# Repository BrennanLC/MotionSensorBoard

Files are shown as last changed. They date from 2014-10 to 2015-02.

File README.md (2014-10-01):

Motion Sensor Board
==============

Wireless motion sensor board that interfaces with parallax PIR sensor.
Board uses the Attiny2313A microcontroller. wireless capability provided by Xbee Pro Series 2 module.

Current version of motion sensor board verified on 9/28/14

Files:

MotionSensorsch.pdf - Copy of board schematic in PDF format
MotionSensorBoard.sch - Board schematic eagle file 
MotionSensorBoard.brd - Board layout eagle file
MotionSensorBoard.pdf - Board layout in PDF format
Gerbers.zip - Gerber board files

schematic and board layout built with Eagle 6.4.0 Standard. More info and 
download available here:

https://www.cadsoftusa.com/

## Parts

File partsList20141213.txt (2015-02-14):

Partlist exported from /Users/BrennanC/Documents/Projects/GitHub/MotionSensorBoard/MotionSensorBoard.sch at 12/13/14 2:37 PM

Part      Value            Device                    Package          Description                                                                                                                              DIGIKEYPART#            PROD_ID     VALUE     
C1        10uF             CAP_POL_AL                PANASONIC_BMIN   Panasonic Aluminum Electrolytic Capacitor Package B                                                                                                                                    
C2        10uF             CAP_POL_AL                PANASONIC_BMIN   Panasonic Aluminum Electrolytic Capacitor Package B                                                                                                                                    
C3        0.1uF            CAP0603-CAP               0603-CAP         Capacitor                                                                                                                                                                              
C4        0.1uF            CAP0603-CAP               0603-CAP         Capacitor                                                                                                                                                                              
C7        10uF             CAP_POL_AL                PANASONIC_BMIN   Panasonic Aluminum Electrolytic Capacitor Package B                                                                                                                                    
CC_TEXT1  CREATIVE_COMMONS CREATIVE_COMMONS          CREATIVE_COMMONS Creative Commons License summary                                                                                                                                                       
J1        PRGM             AVR_SPI_PRG_6PTH          2X3              AVR ISP 6 Pin                                                                                                                                                                          
J2        POWER_JACKPTH    POWER_JACKPTH             POWER_JACK_PTH   Power Jack                                                                                                                                                                             
JP1                        M03PTH                    1X03             Header 3                                                                                                                                                                               
JP4       M02PTH           M02PTH                    1X02             Standard 2-pin 0.1" header. Use with                                                                                                                                                   
LED4                       LED0603                   LED-0603         LEDs                                                                                                                                                                                   
Q1        BSS138           MOSFET-NCHANNELBSS123LT1G SOT23            Common NMOSFET Parts                                                                                                                                             TRANS-08345           
Q2        BSS138           MOSFET-NCHANNELBSS123LT1G SOT23            Common NMOSFET Parts                                                                                                                                             TRANS-08345           
R1        10k              RESISTOR0603-RES          0603-RES         Resistor                                                                                                                                                                               
R2        4.7k             RESISTOR0603              0603-RES         Resistor                                                                                                                                                                               
R3        4.7k             RESISTOR0603              0603-RES         Resistor                                                                                                                                                                               
R4        PHOTOCELLPTH     PHOTOCELLPTH              PHOTOCELL        CdS photoresistor. This is a low cost way to detect light levels. Resistance decreases with more incoming light. SparkFun SKU: SEN-09088                                               
R5        10k              RESISTOR0603              0603-RES         Resistor                                                                                                                                                                               
R6        4.7k             RESISTOR0603              0603-RES         Resistor                                                                                                                                                                               
R7        4.7k             RESISTOR0603              0603-RES         Resistor                                                                                                                                                                               
R10       270              RESISTOR0603-RES          0603-RES         Resistor                                                                                                                                                                               
STANDOFF1 STAND-OFF        STAND-OFF                 STAND-OFF        #4 Stand Off                                                                                                                                                                           
STANDOFF2 STAND-OFF        STAND-OFF                 STAND-OFF        #4 Stand Off                                                                                                                                                                           
STANDOFF3 STAND-OFF        STAND-OFF                 STAND-OFF        #4 Stand Off                                                                                                                                                                           
STANDOFF4 STAND-OFF        STAND-OFF                 STAND-OFF        #4 Stand Off                                                                                                                                                                           
U$2       XBEE-1B1         XBEE-1B1                  XBEE-1           Xbee module footprints                                                                                                                                                                 
U2        ISO7221ADR       ISO7221ADR                SO08             ISO7221 Dual Channel Digital Isolator from Texas Instruments. See Datasheet for more info Datasheet                                      296-21955-1-ND                                
U3        BMP180           BMP180                    BMP180           BOSCH BMP180 DIGITAL BAROMETRIC PRESSURE SENSOR                                                                                                                                        
U4        NCP1117ST50T3G   NCP1117ST50T3G            SOT223           NCP1117 5V, 1.0 A Low-Dropout Positive Fixed and Adjustable Voltage Regulator  Datasheet                                                 NCP1117ST50T3GOSCT-ND                         
U5        LM1117MPX-3.3    LM1117MPX-3.3             SOT223           3.3V Low Dropout Regulator, 0.8A output. See datasheet for more info Datasheet                                                           LM1117MPX-3.3/NOPBCT-ND                       
U6        HTU21DSMD        HTU21DSMD                 HTU21D                                                                                                                                                                                                  
U7        ATMEGA328P       ATMEGA328_SMT             TQFP32-08        32-Pin Atmega328 part                                                                                                                                            IC-09069    ATMEGA328P

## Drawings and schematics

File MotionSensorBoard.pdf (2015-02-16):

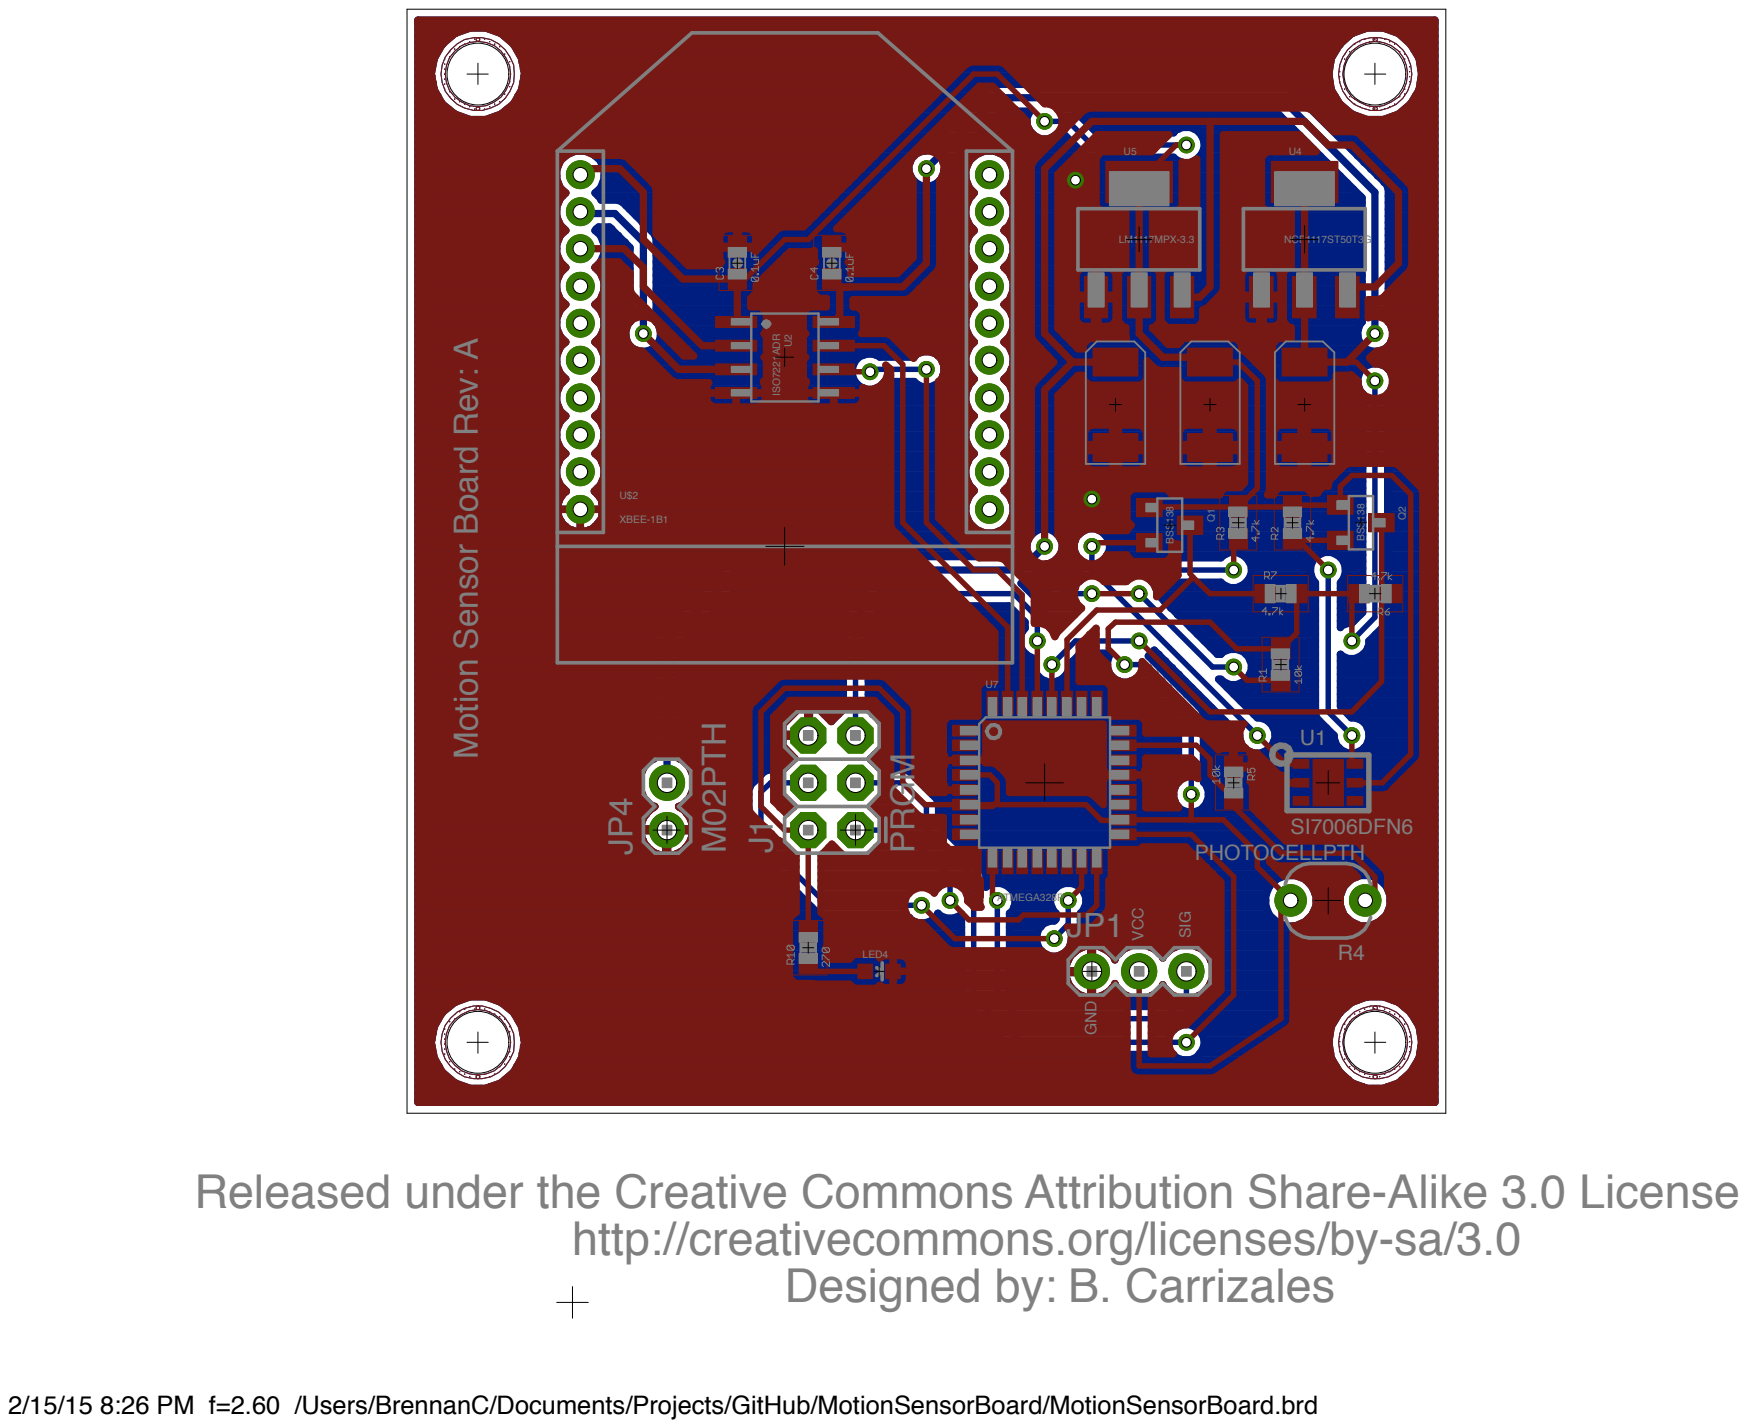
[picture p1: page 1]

LM1117MPX-3.3 | NCP1117ST50T3G

XBEE-1B1

Released under the Creative Commons Attribution Share-Alike 3.0 License

http://creativecommons.org/licenses/by-sa/3.0

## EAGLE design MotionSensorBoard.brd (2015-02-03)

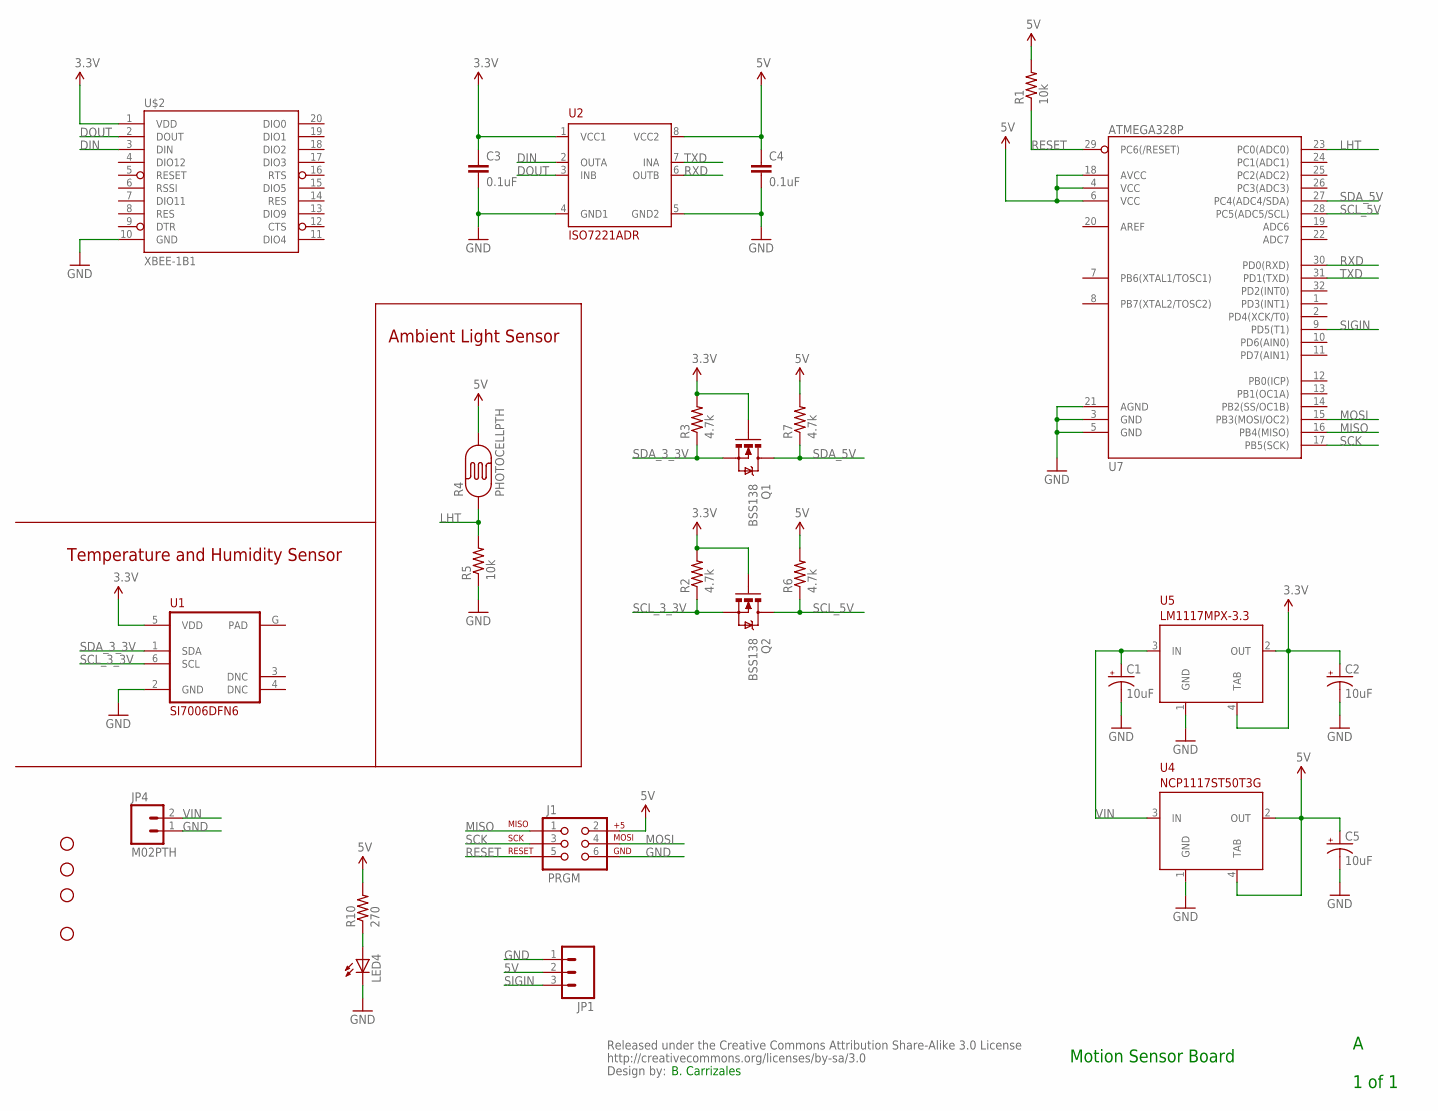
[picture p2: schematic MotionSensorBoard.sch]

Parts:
C1, C2, C5: 10uF; EIA6032
C3, C4: 0.1uF; 0603-CAP
CC_TEXT1: CREATIVE_COMMONS
J1: PRGM; 2X3
JP1: M03PTH; 1X03
JP4: M02PTH; 1X02
LED4: LED0603; LED-0603
Q1, Q2: BSS138; SOT23
R1, R5: 10k; 0603-RES
R2, R3, R6, R7: 4.7k; 0603-RES
R4: PHOTOCELLPTH; PHOTOCELL
R10: 270; 0603-RES
STANDOFF1, STANDOFF2, STANDOFF3, STANDOFF4: STAND-OFF
U1: SI7006DFN6; DFN-6
U2: ISO7221ADR; SO08
U4: NCP1117ST50T3G; SOT223
U5: LM1117MPX-3.3; SOT223
U7: ATMEGA328P; TQFP32-08
U$2: XBEE-1B1; XBEE-1

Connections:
3.3V: C2.P$1 (+), C3.1, Q1.1 (G), Q2.1 (G), R2.2, R3.2, U1.5 (VDD), U2.1 (VCC1), U5.2 (OUT), U5.4 (TAB), U$2.1 (VDD)
5V: C4.1, C5.P$1 (+), J1.2, JP1.2, R1.2, R4.2, R6.2, R7.2, R10.2, U2.8 (VCC2), U4.2 (OUT), U4.4 (TAB), U7.4 (VCC), U7.6 (VCC), U7.18 (AVCC)
DIN: U2.2 (OUTA), U$2.3 (DIN)
DOUT: U2.3 (INB), U$2.2 (DOUT)
GND: C1.P$2 (-), C2.P$2 (-), C3.2, C4.2, C5.P$2 (-), J1.6, JP1.1, JP4.1, LED4.C, R5.1, U1.2 (GND), U2.4 (GND1), U2.5 (GND2), U4.1 (GND), U5.1 (GND), U7.3 (GND), U7.5 (GND), U7.21 (AGND), U$2.10 (GND)
LHT: R4.1, R5.2, U7.23 (PC0(ADC0))
MISO: J1.1, U7.16 (PB4(MISO))
MOSI: J1.4, U7.15 (PB3(MOSI/OC2))
unnamed: LED4.A, R10.1
RESET: J1.5, R1.1, U7.29 (PC6(/RESET))
RXD: U2.6 (OUTB), U7.30 (PD0(RXD))
SCK: J1.3, U7.17 (PB5(SCK))
SCL_3_3V: Q2.2 (S), R2.1, U1.6 (SCL)
SCL_5V: Q2.3 (D), R6.1, U7.28 (PC5(ADC5/SCL))
SDA_3_3V: Q1.2 (S), R3.1, U1.1 (SDA)
SDA_5V: Q1.3 (D), R7.1, U7.27 (PC4(ADC4/SDA))
SIGIN: JP1.3, U7.9 (PD5(T1))
TXD: U2.7 (INA), U7.31 (PD1(TXD))
VIN: C1.P$1 (+), JP4.2, U4.3 (IN), U5.3 (IN)

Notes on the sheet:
Motion Sensor Board
1 of 1
B. Carrizales
Temperature and Humidity Sensor
Ambient Light Sensor

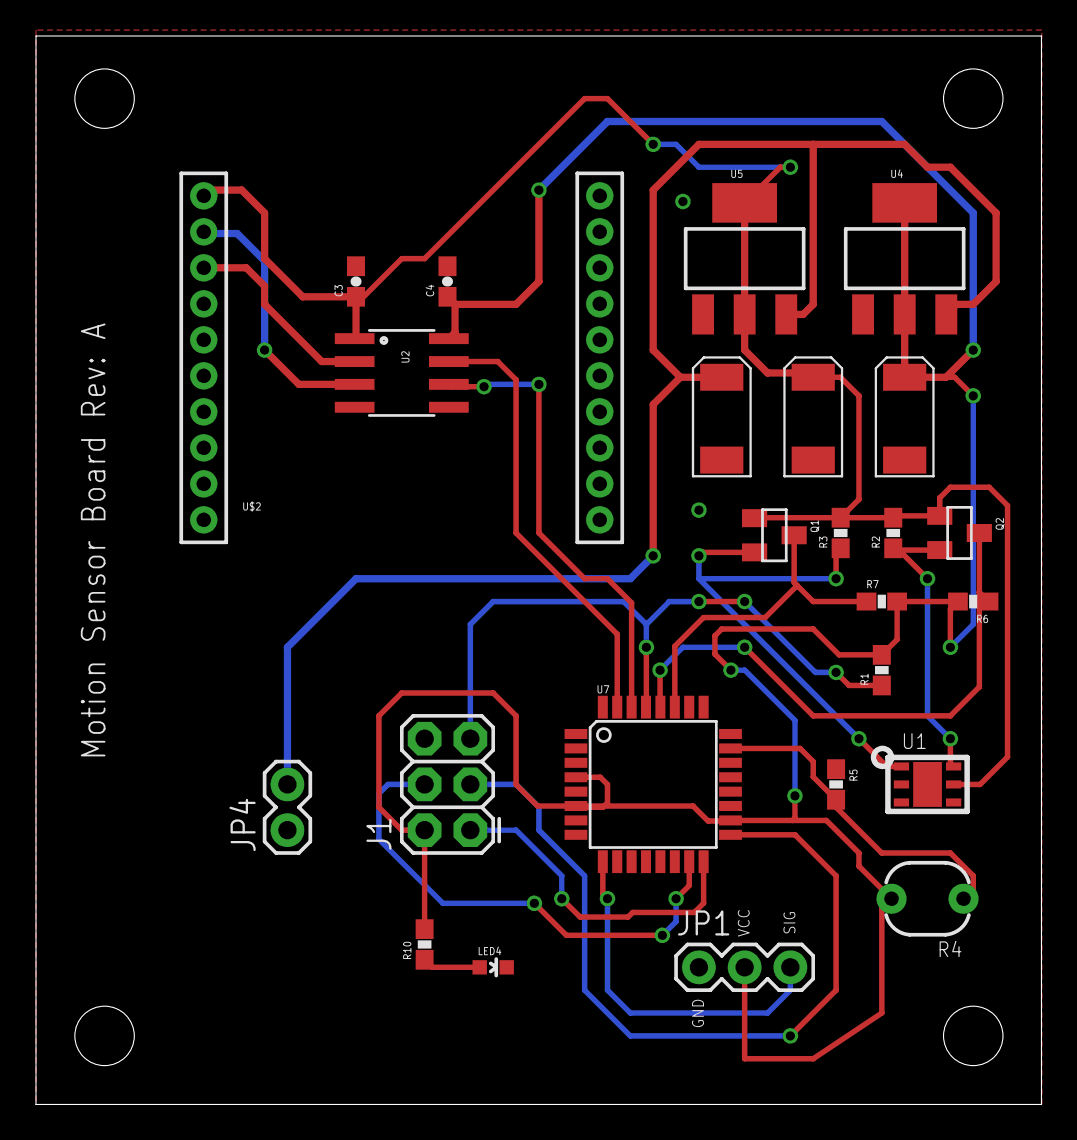
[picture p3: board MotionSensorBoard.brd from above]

Board: 2 copper layers, 55.9 x 59.4 mm, 30 parts (0 on the bottom side), 19 nets.

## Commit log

2014-02-20 Initial Commit
    Initial Commit
    [MotionSensorBoard.brd, MotionSensorBoard.sch]
2014-02-27 Added Gerber Files
2014-10-01 Update README.md
    Board fully verified
2014-11-15 updated schematic
    [MotionSensorBoard.brd, MotionSensorBoard.sch]
2014-11-16 Schematic Updated
    Schematic Rev A major revisions complete
    [MotionSensorBoard.brd, MotionSensorBoard.sch]
2015-02-03 updated board layout and generated Gerbers
    [MotionSensorBoard.brd, MotionSensorBoard.sch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]
2015-02-14 updated parts list
    [PartsList20141213.csv]

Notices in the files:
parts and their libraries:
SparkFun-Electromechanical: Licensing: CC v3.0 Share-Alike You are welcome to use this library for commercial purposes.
